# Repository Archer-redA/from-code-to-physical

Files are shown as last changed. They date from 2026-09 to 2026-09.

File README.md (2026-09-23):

# 从代码到实物 · 课程仓库

> **软件工程 · 张涛**
> 学期项目：**一体打印的可动机械键盘模型（macropad）**
> 已完成练习：**ARCHER 名字戒指**（3D 打印）



---

## 一、我是谁

- **专业**：软件工程
- **姓名**：张涛
- **GitHub**：[@Archer-redA](https://github.com/Archer-redA)

## 二、为什么选这门课

写了几年代码，但产出基本都停在屏幕里 —— 一个网页、一个脚本、一个跑在终端里的程序。它们能运行、能演示，但摸不到、拿不走。

我想试试另一条路：**让代码去驱动一个真实存在的东西**。按下按键，它要有反应；改一行配置，行为要真的跟着变。

这门课的名字恰好就是我想解决的问题 —— 「从代码到实物」。软件这一侧我相对熟悉，而电路、焊接、外壳、调试这些对我来说是全新的，正好是我想补的那一块。选它，是想给自己加一个约束：**必须动手，必须把东西真的做出来**，而不是又停在 `npm run dev`。

## 三、这学期想造什么

**一个一次打印成型、打出来就能动的机械键盘模型（macropad）。**
按下按键会下沉并自动回弹，转动旋钮会连续旋转 —— **不用组装、不用螺丝、不用五金件**。

> **第 1 周修订说明**：这个项目最初定的是「带电子功能的宏键盘」，我把它改成了
> **无电子功能的可动模型**。原因不是放弃，而是排优先级：原方案要串起主控、轴体、
> 焊接、固件、上位机工具，链路太长，依赖的零件也多，第一个学期很难在保证质量的前提下
> 全部做完。改成模型之后，同样的时间可以花在**机构设计**上 ——
> 柔性铰链、配合公差、可打印性。这些是更根本、也更容易被忽略的工程能力。
> 电子功能留作后续可选延伸，见需求文档第 6 节。

选它的理由：

1. **规模可控但难度不低。** 6 个键 + 1 个旋钮，尺寸不大，但「一体打印还要能动」
   是有真实技术门槛的 —— 见下方「这个项目难在哪」。
2. **逼着学公差。** 前面那个戒指是静态件，形状对就能打；这个项目必须处理
   **间隙、应变、桥接**，是从「建模」跨到「机构」的一步。
3. **一次打印、零装配。** 拿下来就是成品，非常适合演示，也不怕零件丢。
4. **仍然指向真实键盘。** 柔性机构、键位间距、结构刚度这些经验，
   以后真做一把能用的键盘时全部用得上。

### 这个项目难在哪

有一个本质矛盾必须在建模阶段解决：

> **柔性件要能动，周围就得是空的；但空的地方打印时没有支撑，材料会塌。**

传统解法是加支撑，但一加支撑就不是「一体打印、免组装」了。

**解法是把柔性梁做成「桥」** —— 两端都搭在实体墙上，中间悬空：

- **打印时**：它是一段桥，两端有支撑，桥接没问题 ✅
- **受力时**：它是一根两端固定的梁，中间能下沉、能回弹 ✅

代价是两端固定的梁比悬臂梁刚 8 倍，同样行程下应变高 8 倍，所以行程只能做到
**约 1.2mm**、应变控制在 **1.3% 以内**（PLA 反复弯曲的安全区）。

### 期末最低验收目标

- **至少 6 个按键**，每个都能按下并自动回弹，行程 ≥ 0.8mm
- **至少 1 个旋钮**，能连续旋转 360° 以上
- **一次打印成型**，不需要支撑材料，不需要任何组装
- 单键反复按压 **≥ 500 次**不失效

完整的验收标准、非目标与里程碑见 [`docs/需求与验收标准.md`](docs/需求与验收标准.md)。

## 四、仓库结构

```
.
├── README.md                  # 本文件
├── .gitignore
├── docs/
│   ├── 需求与验收标准.md        # 这个项目要做什么、怎么才算做完
│   ├── 工具链搭建.md            # 开发环境清单与逐项验证记录
│   └── 踩坑记录.md              # 卡得最久的问题 + 怎么解决的
├── hardware/
│   ├── ring/                  # ARCHER 名字戒指：建模源文件 + STL + 预览图 + 实拍
│   │   ├── ring.scad          # 参数化建模脚本（改这个）
│   │   ├── ring.stl           # 可直接切片的成品
│   │   ├── photo-printed.jpg  # 实物照片
│   │   └── README.md          # 尺寸、打印参数、校验记录、已知取舍
│   └── macropad/              # 学期项目：一体打印可动机械键盘模型
│       ├── key-test.scad      # 单键柔性机构测试件（先验证再放大）
│       ├── macropad.scad      # 整机（后续）
│       └── README.md          # 机构原理、应变计算、打印实测
└── tools/
    └── stl-check.js           # STL 水密性/流形校验工具
```

后续阶段计划增加的目录：

| 目录 | 用途 | 预计出现时间 |
|---|---|---|
| `hardware/macropad/` 旋钮测试件 | 旋转机构独立验证 | 第 3 周 |
| `hardware/macropad/` 整机 | 6 键 + 旋钮完整模型 | 第 4–5 周 |

## 五、开发环境（工具链）

本学期使用的工具链，均已实测通过：

| 用途 | 工具 | 版本 | 验证方式 |
|---|---|---|---|
| 版本控制 | Git | `2.20.1.windows.1` | `git --version` |
| 远程仓库 | GitHub（**SSH over 443**） | — | `ssh -T git@github.com` |
| 代码编辑器 | VS Code | `1.133.0` | `code --version` |
| 脚本 / 上位机工具 | Node.js / npm | `v24.14.1` / `11.11.0` | `node --version` |
| 三维建模 | OpenSCAD | `2026.09.16` | `openscad --info` |
| 3D 打印机 | Bambu Lab A1 mini | FDM / 0.4mm 喷头 | — |

> ⚠️ **本机 HTTPS 方式访问 GitHub/Gitee 不可用**，已改用 SSH。原因、复现步骤与解决方案见 [`docs/踩坑记录.md`](docs/踩坑记录.md)。

> ⚠️ **OpenSCAD 的 `textmetrics()` 是实验性函数，默认关闭。**
> 图形界面需在「编辑 → 首选项 → 功能(Features)」里勾选 `textmetrics`，
> 命令行渲染需加 `--enable=textmetrics`。详见 `hardware/ring/README.md`。

详细的环境清点、缺口与补齐计划见 [`docs/工具链搭建.md`](docs/工具链搭建.md)。

## 六、第一件实物：ARCHER 名字戒指

**已经真的打印出来了**（2026-09-23，Bambu Lab A1 mini）：

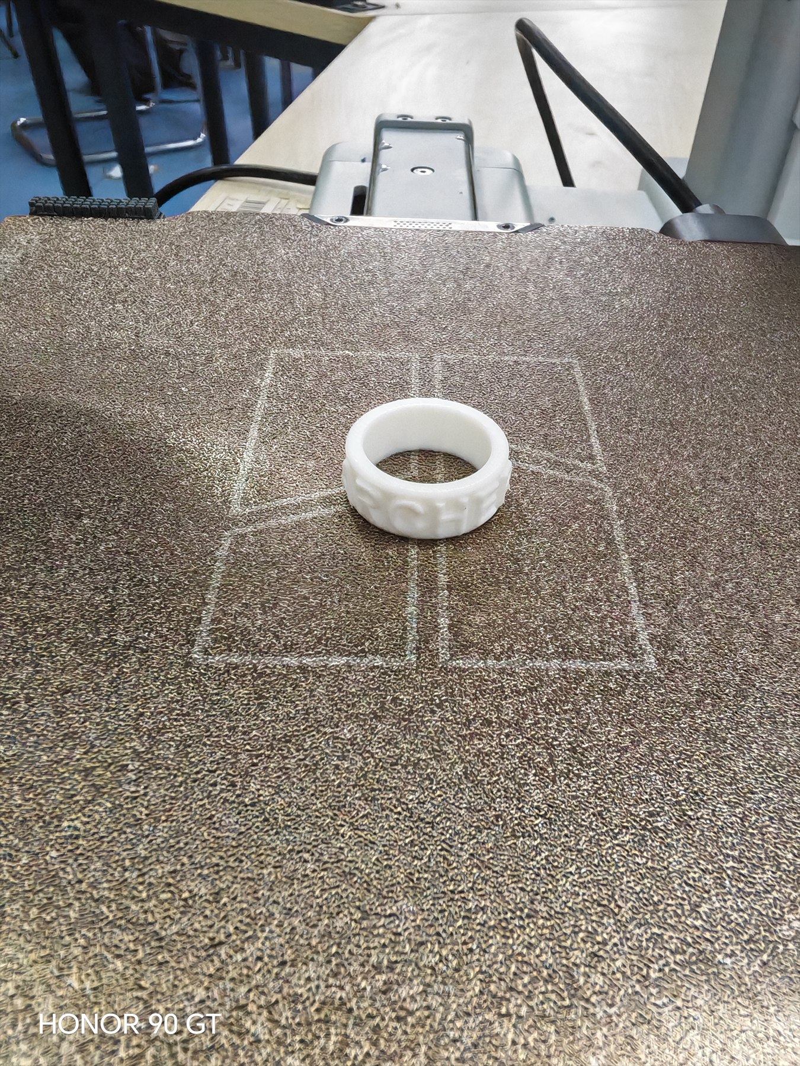
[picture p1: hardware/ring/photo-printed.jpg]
实物照片


这是建模阶段的渲染图，可以和上面的实物对比设计意图与实际结果：

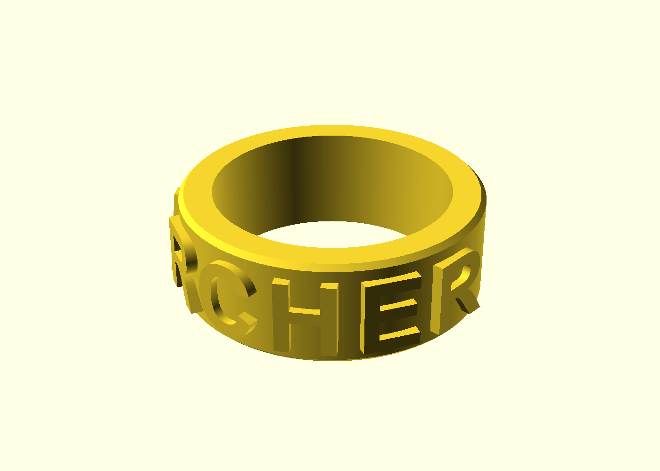
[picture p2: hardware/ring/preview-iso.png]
等轴测预览


把名字刻在戒指外圈，文字绕环 176°。**不是手动捏出来的，是写代码生成的** ——
整个模型由一个参数化脚本描述，改一个数字就能改尺寸、改文字。

| 项目 | 数值 |
|---|---|
| 外径 / 内径 / 带宽 / 壁厚 | 23 / 18 / 8 / 2.5 mm |
| 字高 / 凸起高度 | 5.5 mm / 0.6 mm |
| 网格体积 | 1335.8 mm³ |
| 预计耗材 | 约 1.66 g（PLA） |
| 水密性校验 | 开边 0、非流形 0、退化 0 —— **通过** |
| 实际打印 | 2026-09-23 完成，**一次成功**，耗时约 10 分钟，**效果良好** |

完整尺寸、打印参数、建模取舍与实拍记录见 [`hardware/ring/README.md`](hardware/ring/README.md)。

**这一步学到的三件事：**

1. **摆放方向决定成败。** 平放（轴向竖直）时文字全是垂直棱柱，零悬垂、不用支撑；
   立着放则下半圈整体是大角度悬垂，必然塌边。同一个模型，换个方向就是能用和不能用。
2. **打印机能打多细，是设计约束不是事后调参。** 0.4mm 喷头意味着笔画宽度不能低于
   0.8mm 左右，所以字必须用粗体 —— 这是设计阶段就要定下来的事。
3. **先校验再切片。** 自己写了个工具检查网格是否水密、是否流形，
   在源头把问题验掉，比在切片软件里看到莫名其妙的警告再回头查省事得多。
   这次模型一次打印成功、没出任何网格报错，验证了这一步是有效的。
4. **推荐参数和实际参数是两回事。** 我给的推荐层高是 0.12mm，但实际打印只花了约
   10 分钟，明显快于该预设的预期 —— 说明实际用的大概率是更快的档位。
   所以文档里「推荐值」和「实际值」必须分开记，否则下次照着推荐值打，
   永远不知道真实差异出在哪。

## 七、进度计划

| 周次 | 目标 | 状态 |
|---|---|---|
| 第 1 周 | 工具链搭建、仓库建立、需求与验收标准定稿 | ✅ 已完成 |
| 第 1 周 | 3D 建模环境就绪，完成 ARCHER 名字戒指并校验网格 | ✅ 已完成 |
| 第 1 周 | 戒指实际打印完成（A1 mini，一次成功） | ✅ 已完成 |
| 第 1 周 | 学期项目范围修订为「一体打印可动模型」 | ✅ 已完成 |
| 第 2 周 | **单键柔性机构测试件**：应变验证 + 500 次按压实测 | 🔄 进行中 |
| 第 3 周 | 旋钮机构独立验证 | ⬜ 未开始 |
| 第 4–5 周 | 整机建模：6 键 + 1 旋钮 | ⬜ 未开始 |
| 第 6 周 | 整机首次打印，F1–F8 全部验收 | ⬜ 未开始 |
| 第 7–8 周 | 迭代与加分项（段落感 / 旋钮定位 / 曲面键帽） | ⬜ 未开始 |
| 第 9 周 | 整机联调、文档收尾、期末演示准备 | ⬜ 未开始 |

---

*本仓库为《从代码到实物》课程学期项目仓库，将持续更新至期末。*

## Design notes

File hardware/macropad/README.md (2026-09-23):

# 单键柔性机构测试片

> **目的：在做整机之前，先验证「桥式柔性梁」这个机构能不能成立。**
> 一片上放三个变体，一次打印验证三种刚度。

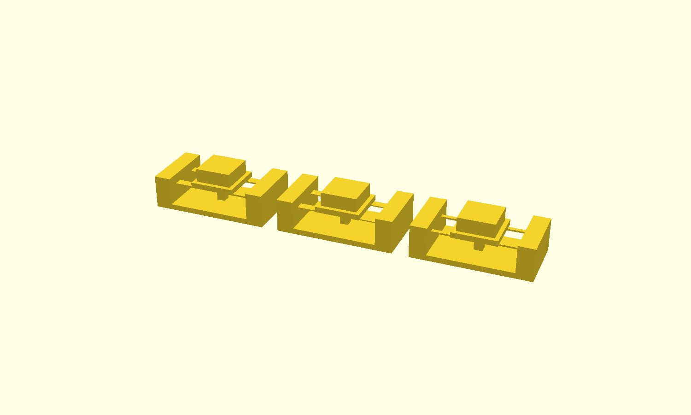
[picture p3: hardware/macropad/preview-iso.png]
等轴测


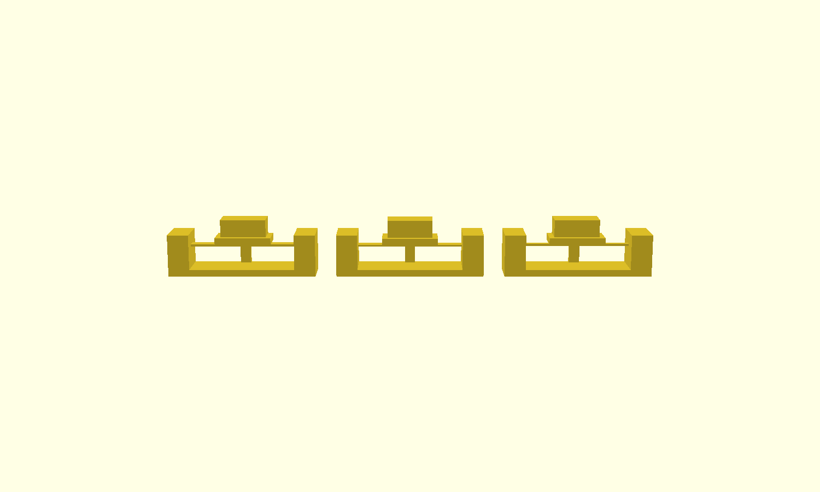
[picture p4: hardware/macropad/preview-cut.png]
剖视（露出梁、平台、止挡柱）


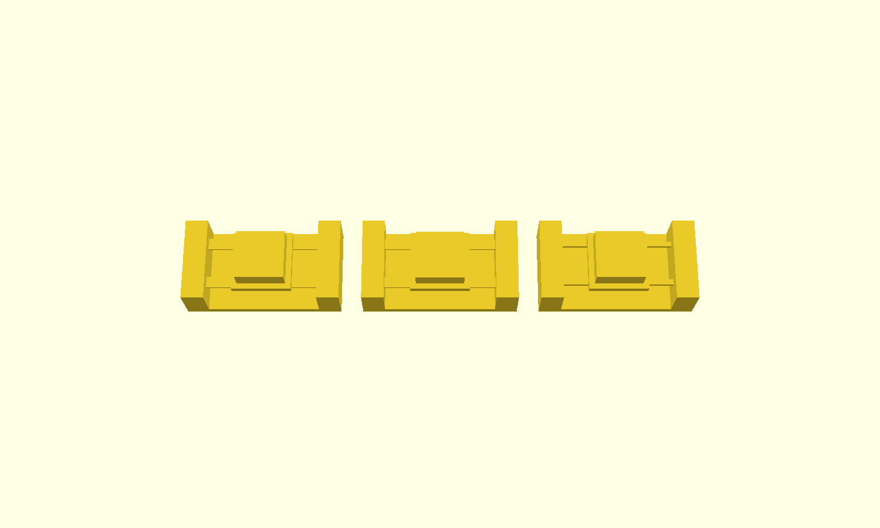
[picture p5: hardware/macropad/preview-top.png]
俯视（三个变体并排，共用一套打印参数）


## 要解决的核心矛盾

一体打印的可动件有一个本质矛盾：

> **柔性件要能动，周围就得是空的；但空的地方打印时没有支撑，材料会塌。**

加支撑就违背了「一体打印、免组装」的前提。

**解法：把柔性梁做成「桥」** —— 两端都搭在实体墙上，中间悬空。

| | 打印时 | 受力时 |
|---|---|---|
| 桥式梁 | 一段桥，两端有支撑，桥接没问题 ✅ | 一根两端固定的梁，中间能下沉、能回弹 ✅ |

代价：两端固定的梁比悬臂梁**刚 8 倍**（端部弯矩大），同样行程下应变也高 8 倍。

## 力学计算

两端固定梁 + 中央集中载荷：

```
弯曲刚度     I = b·t³ / 12
单根梁刚度   k = 192·E·I / L³
最大应变     ε = 12·t·δ / L²      （应变在两端的固定处最大）
```

PLA 取 E ≈ 3500 MPa，L = 30mm，设计行程 δ = 1.5mm：

| 变体 | 梁厚 t | 梁宽 b | 厚度层数 | 刚度 k | 压到底需 | ε @1.5mm | ε 达 1.5% 时行程 |
|---|---|---|---|---|---|---|---|
| **A** | 0.6 mm | 3.0 mm | 3 | 2.69 N/mm | 4.03 N | 1.20% | 1.88 mm |
| **B** | 0.4 mm | 3.0 mm | 2 | 0.80 N/mm | **1.19 N** | 0.80% | 2.81 mm |
| **C** | 0.6 mm | 1.5 mm | 3 | 1.34 N/mm | 2.02 N | 1.20% | 1.88 mm |

**参照**：Cherry MX 红轴 45 gf ≈ 0.45 N，黑轴 60 gf ≈ 0.6 N。
所以三个变体都偏硬，**B 最接近真实手感**，但它只有 2 层厚，是三个里最脆的 ——
这正是要实测的东西：**理论上最合适的设计，打印出来到底扛不扛得住。**

> **1.5% 应变的来历**：PLA 的断裂延伸率约 3–6%，但反复弯曲要考虑疲劳，
> 安全区取 1.5% 以下。**超过这个值不会立刻断，而是按几次之后出现永久变形或裂纹。**

## 止挡设计

首次打印**不要**去掉止挡柱。理由：

- 柔性梁的应变与实际行程成正比，**人手上按多重是不可控的**
- 没有止挡时，用力一按就可能把梁压到 3% 应变以上，直接产生永久变形
- 止挡柱让行程硬性停在设计值，**梁的应变不会超过计算值**

止挡柱从底板上长出来，柱顶与平台底面之间正好留出 `TRAVEL`。

> ⚠️ 第一版我漏了底板，导致止挡柱**完全悬空** —— 打出来会是一根 3×3×6.5mm 的
> 散件掉在壳子里，根本起不到止挡作用。这个问题是**用连通分量检测抓出来的**，
> 见下节。已修复。

## 校验

```bash
node ../../tools/stl-check.js key-test.stl 0.000001 3
```

```
triangles    : 432
size (mm)    : X=138  Y=22  Z=15.6
open edges   : 0
non-manifold : 0
degenerate   : 0
components   : 3 (expected 3)  sizes: 144 + 144 + 144 tris
结论          : 通过 —— 水密流形，可以打印
```

**第三个参数 `3` 是预期的连通分量数。** 这个参数是为一体打印件专门加的：

- 一体打印的零件**必须是连通的**，分开的壳体会变成打出来掉在里面的散件
- 而**切片软件不会为此报警** —— 它照样能把两个分离的实体切成两个独立的打印件，只是你不知道
- 所以必须自己验：每个变体是一个分量，三个变体就是三个分量
- **三个分量大小完全相等（144+144+144）**，说明每个变体内部都是连通的，止挡柱没掉

## 打印参数

| 参数 | 取值 | 说明 |
|---|---|---|
| 层高 | **0.2 mm** | **梁厚必须是层高的整数倍**，否则实际厚度不由你控制 |
| 支撑 | **关闭** | 桥式梁本来就是为了免支撑设计的 |
| 摆放 | 平放，与脚本朝向一致 | 不要旋转模型 |
| 墙数 | 3 | |
| 填充 | 15% | |

**层高这条特别重要**：变体 B 的梁设计厚度是 0.4mm，如果层高是 0.3mm，切片软件
只能给你 0.3 或 0.6mm —— 那刚度和应变跟算出来的完全对不上，测试就白做了。

## 怎么测

打印完成后，逐个按下三个键（从左到右是 A / B / C）：

| 检查项 | 合格标准 |
|---|---|
| 能否按下 | 三个都能明显下沉 |
| 回弹 | 松手后回到原位，无残留变形 |
| 相邻独立 | 按一个键时旁边的键不动（这一片是独立单元，主要测整机时用） |
| **按压 500 次** | 用拇指连续按，不出现白化、裂纹、断裂 |
| 手感排序 | 记录 A/B/C 哪个最舒服，与计算值对比 |

**建议把结果记回来**（改这一节就行）：

| 变体 | 实测手感 | 500 次后状态 |
|---|---|---|
| A | 待填 | 待填 |
| B | 待填 | 待填 |
| C | 待填 | 待填 |

## 参数怎么改

都在 `key-test.scad` 顶部：

```openscad
SPAN    = 30;     // 自由跨距 —— 应变 ∝ 1/L²，这是最有效的调节手段
TRAVEL  = 1.5;    // 设计行程 —— 同时决定止挡柱高度
VARIANTS = [      // [梁厚, 梁宽]
    [0.6, 3.0],
    [0.4, 3.0],
    [0.6, 1.5],
];
```

**跨距不能随便加大**：`SPAN` 同时是桥接长度，超过约 35mm 打印时会塌。
这是「机构设计」和「可打印性」直接冲突的地方 —— **也是这个项目最难的一处权衡**。

出图时控制台会打印每个变体的刚度、所需压力、应变，改完直接看数字即可。
`CUT = 1` 可以出一张剖视图，用来检查梁、平台、止挡柱的相对位置。

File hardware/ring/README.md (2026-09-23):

# ARCHER 名字戒指

第一件实物练习：把建模代码变成能打印出来的东西。
名字刻在戒指外圈，绕环约 **176°**。

## 实物

实物照片

*2026-09-23 打印完成。照片已压缩并清除 EXIF（原始 3000×4000 / 7.2MB →
1350×1800 / 933KB）。*

### 实际打印记录

| 项目 | 实际值 |
|---|---|
| 打印机 | Bambu Lab A1 mini，0.4mm 喷嘴 |
| 打印日期 | 2026-09-23 |
| **实际耗时** | **约 10 分钟** |
| 实际层高 | 未记录 |
| 实际耗材 | 未记录 |
| 实际用量 | 未称重 |

### 打印效果评估

**结论：整体效果不错，文字清晰可用。**

判断主要归功于两个设计选择：**环体做得厚、做得大**（壁厚 2.5mm、带宽 8mm、
外径 23mm），以及**字做得大**（字高 5.5mm）。前者让结构本身不脆弱、不易翘曲变形，
后者让笔画有足够宽度可供 FDM 完整还原。

这两点在建模阶段不是随手定的，是为了满足 0.4mm 喷头的可打印性下限（详见下节
「为什么字必须用粗体」）而刻意选的。**实测证明这个方向是对的**。

反过来说，如果把这个设计缩小一半（比如做成真正的细戒圈），文字笔画会同步缩到
0.5mm 左右，落到单条挤出线的宽度——那时候"能不能打清楚"就完全是另一个问题了。
**小尺寸不是等比缩小，是重新设计。**

> ⚠️ **注意耗时与推荐参数不匹配。**
> 上表「打印参数」一节推荐的是 `0.12mm Fine` 预设，按该预设估算这个件要二十几分钟。
> 实测 10 分钟完成，说明**实际很可能用的是默认的 `0.20mm Standard` 预设**（或更快的档位）。
> 层高越粗，0.6mm 的文字凸起只够 3 层，文字的侧面锐利度会下降。
> **下次打印建议显式确认层高设置**，并对比两种层高的文字清晰度差异。

### 渲染 vs 实物

| | 渲染图（建模输出） | 实物（实际打印） |
|---|---|---|
| 来源 | `preview-iso.png` | `photo-printed.jpg` |
| 用途 | 确认设计意图 | 确认真的做出来了 |

## 渲染图

等轴测预览

## 文件说明

| 文件 | 说明 |
|---|---|
| `ring.scad` | **参数化建模源文件**（改这个，不要改 STL） |
| `ring.stl` | 可直接切片的成品网格（二进制 STL，9720 三角形） |
| `photo-printed.jpg` | **实物照片**（已清除 EXIF） |
| `preview-iso.png` | 等轴测预览 |
| `preview-hero.png` | 主视角预览 |
| `preview-front.png` | 正侧视预览（名字正对镜头） |
| `preview-top.png` | 俯视预览（看内外径比例） |

## 设计尺寸（从 STL 实测，非设计值）

| 项目 | 数值 |
|---|---|
| 环体内径 | 18.00 mm |
| 环体外径 | 23.00 mm |
| 文字凸起后最大半径 | 24.76 mm（含字母两端） |
| 带宽 | 8.00 mm |
| 壁厚 | 2.50 mm |
| 字高 | 5.50 mm |
| 文字凸起高度 | 0.60 mm |
| 文字绕环角度 | 176.0° |
| 网格体积 | 1335.8 mm³ |
| 预计耗材 | 约 **1.66 g**（PLA，密度 1.24 g/cm³） |
| 预计耗材长度 | 约 555 mm（1.75mm 线径） |
| 网格三角形 | 9720 |
| 水密性 | 开边 0、非流形 0、退化 0（校验通过） |

耗材量是按网格体积换算的。**打印时间请以 Bambu Studio 切片后的估算为准。**

## 打印参数（推荐值，Bambu Lab A1 mini）

| 参数 | 取值 | 原因 |
|---|---|---|
| 喷头 | 0.4 mm | A1 mini 标配 |
| 层高 | **0.12 mm** | 文字只有 0.6mm 凸起，层高太粗会看不出层次 |
| 摆放 | **平放**（戒指轴向竖直） | 关键：这样文字全是垂直棱柱，Z 方向没有悬垂面 |
| 支撑 | **关闭** | 平放后不需要；开了反而会粘在字上 |
| 墙数 | 4 | 壁厚 2.5mm，4 圈墙就基本填满了 |
| 填充 | 15% | 实际几乎全由墙填满，填充率影响很小 |
| 底座(Brim) | 3 mm（可选） | 首层是个 23mm 的圆环，附着力够，加个 Brim 更保险 |

> ⚠️ **不要立着放。** 立放时环的下半圈整体是大角度悬垂，必然塌边。
> 平放是这个小件唯一合理的摆法。

## 为什么字必须用粗体

这是 FDM 打印能不能看清文字的硬约束：

- A1 mini 喷头 0.4mm，单条挤出线宽约 0.42mm
- 实测 Arial Bold 在字高 5.5mm 时，竖笔画约 **1.07mm** ≈ 2.5 条挤出线 → 能连住
- 同样的字高换成常规字重，笔画只剩约 0.65mm ≈ 1.5 条线 → 打印时容易断线、糊成一团

所以 `FONT` 参数一定要带 `:style=Bold`。

## 怎么改

所有尺寸都在 `ring.scad` 顶部，改一个数重新出图即可，不需要重画：

```openscad
INNER_D = 18;        // 内径
WALL    = 2.5;       // 壁厚
BAND    = 8;         // 带宽
TEXT    = "ARCHER";  // 刻什么字
CAP     = 5.5;       // 字高
EMBOSS  = 0.6;       // 凸起高度
```

**改完记得核对弧长**：字太长会绕环超过一圈，字与字会自己压在一起。
出图时 OpenSCAD 会打印一行 `TEXT_SPAN_DEG`，**这个值不要超过 330°**，留出空隙。

## 怎么重新生成

```bash
# 生成 STL（二进制）
openscad --enable=textmetrics --export-format binstl \
         -o ring.stl ring.scad

# 生成预览图
openscad --enable=textmetrics --render --imgsize=1400,1000 \
         --projection=p --autocenter --viewall \
         --camera=0,0,0,60,0,25,60 -o preview-iso.png ring.scad
```

> ⚠️ **`--enable=textmetrics` 不能省。**
> `textmetrics()` 在 OpenSCAD 里是实验性内置函数，默认关闭。
> 图形界面里打开方式：**编辑 → 首选项 → 功能(Features) → 勾选 textmetrics**。
> 没有它的话，脚本会自动回退到文件内烘焙好的字宽表，仍然能出图，
> 但遇到表里没有的字符会按估算宽度排，字距会不准。

## 校验

打印前用仓库自带的工具验过水密性：

```bash
node ../tools/stl-check.js ring.stl
```

结果：

```
triangles    : 9720
open edges   : 0
non-manifold : 0
degenerate   : 0
CONCLUSION   : 通过 —— 水密流形，可以打印
```

**为什么要做这一步**：切片软件对非水密网格的处理方式不一致，可能出现
「有的地方凭空多一层墙」或者直接报错。先在源头验掉，比在切片软件里
看到莫名其妙的警告再回头查省事得多。

**事后验证**：这个模型确实一次打印成功，没有出现网格相关的报错，说明校验是有效的。

## 已知取舍

建模时明确知道、但选择接受的地方，记下来免得以后忘了：

1. **每个字母是一块切平面上的平板，不是真正贴着圆柱弯曲的。**
   代价是字母两端的凸起比中间多约 0.28mm（0.6mm → 0.88mm），
   看上去字的两端略高一点点。
   要做成完全等高的弯曲文字，得把每个字母切成上百个薄片再绕圆周旋转，
   会引入新的接缝问题，而且网格量大一个数量级。
   对这个尺寸的装饰件，0.28mm 的差异在 0.4mm 喷头下基本看不出来，选了简单可靠的方案。

2. **内圈边缘没有倒角。** 外圈上下棱有 0.4mm 倒角，内圈是直角。
   反正是戴着玩的装饰件，内圈不做处理不影响打印。

3. **不支持中文。** 中文笔画密，5.5mm 字高下笔画只有 0.3mm 左右，
   FDM 打印必然糊成一团，要刻中文得换光固化，或者把戒指做大好几倍。

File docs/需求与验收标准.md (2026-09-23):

# 需求与验收标准：一体打印可动机械键盘模型

> 本文档定义本学期项目的**范围**与**完成标准**。
> 目的：避免「做了一半说不清算不算做完」，也让每一周的进展都能对照检查。
>
> ⚠️ **第 1 周修订**：本项目原定为「带电子功能的宏键盘」，现改为
> **一体打印的可动机械模型（无电子功能）**。原方案需要主控、轴体、焊接、
> 固件、上位机工具，链路长、依赖多的零件，第一学期难以在保证质量的前提下完成。
> 改为模型后，可以在同样的时间里把**机构设计**这一块做扎实 ——
> 柔性铰链、配合公差、可打印性，这些是更根本的工程能力。
> 电子功能不是被放弃，而是**留作后续可选延伸**（见第 6 节）。

## 1. 一句话描述

一个打出来就能用的机械键盘模型：**按下按键会下沉并自动回弹，转动旋钮会连续旋转**。
整体一次打印成型，不需要组装、不需要螺丝、不需要任何五金件。

## 2. 目标用户

我自己，以及任何想看看「柔性机构能打印到什么程度」的人。放在桌上是个摆件，拿起来能玩。

## 3. 必做功能（期末必须全部达成）

| 编号 | 功能 | 验收方式 |
|---|---|---|
| F1 | **至少 6 个按键**，每个都能按下并自动回弹 | 逐个按下，松手后全部回到原位，无卡滞 |
| F2 | **至少 1 个旋钮**，能连续旋转 | 手动旋转 360° 以上，转动顺畅无卡死 |
| F3 | **一次打印成型**，不需要任何组装 | 从打印板上取下来即为成品，不使用胶水、螺丝、卡扣装配 |
| F4 | **不需要支撑材料** | 切片时支撑设为关闭，仍能成功打印 |
| F5 | 按键**行程 ≥ 0.8 mm** | 用游标卡尺测量按下前后的高度差 |
| F6 | 每个键**能被单独按下**，不影响相邻键 | 按下一个键时，相邻键的高度变化 < 0.1 mm |
| F7 | 柔性件**反复按压不失效** | 单键连续按压 **≥ 500 次**，不出现裂纹、断裂或永久变形 |
| F8 | 整机外观完整，有外壳形态 | 看得出是一个键盘，键位排列整齐 |

## 4. 加分功能（时间允许才做，不列入必做）

- 按键有**段落感**（按下去有"咔哒"一下的手感，而不是线性下沉）
- 旋钮带**阻尼或分段定位**（转动时有清晰的"格"感）
- 按键表面有**曲面凹陷**，贴合手指
- 外壳底面有**防滑脚垫凹槽**
- 多色打印（有 AMS 的话）

## 5. 明确不做（非目标）

划清范围，避免项目失控：

- ❌ 不做电路、不焊线、不接主控
- ❌ 不做固件、不做 HID 上报、不做免驱识别
- ❌ 不做上位机配置工具
- ❌ 不做真实轴体的兼容（不预留 14×14mm 轴孔）
- ❌ 不追求真实键盘的 3–4mm 行程与手感，0.8–1.5mm 即可
- ❌ 不做多零件装配，坚持一次成型

## 6. 后续可选延伸（不在本学期范围）

如果模型做完还有余力，可以按这个顺序往上加：

1. **改成可插真轴的外壳** —— 需要重做定位板（14×14mm 轴孔、1.5mm 板厚）
2. **加电子功能** —— 手焊直连，RP2040 / Pro Micro 类小板
3. **加固件与上位机** —— 按键映射、配置文件热加载

## 7. 里程碑

| 阶段 | 目标 | 通过标准 |
|---|---|---|
| 第 1 周 | 需求定稿、建模脚本建立 | 本文档定稿，仓库结构就绪 |
| 第 2 周 | **单键测试片**验证柔性机构 | 应变计算通过 + 实物按压 ≥ 500 次不失效 |
| 第 3 周 | 旋钮机构验证 | 独立测试件旋转顺畅，无卡死 |
| 第 4–5 周 | 整机建模 | 6 键 + 1 旋钮完整模型，网格校验通过 |
| 第 6 周 | 整机首次打印 | F1–F8 全部通过 |
| 第 7–8 周 | 迭代与加分项 | 至少完成一项加分功能 |
| 第 9 周 | 收尾 | 文档完整、实拍入库、可演示 |

## 8. 风险与应对

| 风险 | 影响 | 应对 |
|---|---|---|
| **柔性件断裂** | F1/F7 直接不通过 | 先做单键测试片把应变验到 <1.5%；PLA 偏脆，不行就换 PETG |
| **桥接塌陷** | 柔性梁打印出来就废了 | 自由跨距控制在 30mm 以内；必要时把梁加宽改善桥接 |
| **按键互相干涉** | F6 不通过 | 键间留足间隙；相邻键的柔性梁走不同高度层 |
| **实际手感与计算不符** | 需要多次重打 | 参数化脚本，改一个数就能重出；测试片打印成本低 |
| **层间结合强度不足** | 梁从层间裂开 | 柔性梁的弯曲方向尽量落在层内；提高打印温度改善层间结合 |

---

*最后更新：第 1 周（项目范围由「功能宏键盘」修订为「可动模型」）*

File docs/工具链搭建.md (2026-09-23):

# 工具链搭建与验证记录

> 记录时间：第 1 周
> 目的：把本学期开发环境的**实际状态**写清楚 —— 装了什么、什么版本、怎么验证的、还缺什么。

## 1. 最终工具链清单

| 用途 | 工具 | 版本 | 安装位置 |
|---|---|---|---|
| 版本控制 | Git | `2.20.1.windows.1` | `D:\program\git\git\Git\cmd\git.exe` |
| 远程仓库 | GitHub | — | [Archer-redA/from-code-to-physical](https://github.com/Archer-redA/from-code-to-physical) |
| 推送协议 | SSH（**走 443 端口**） | — | `~/.ssh/config` |
| 代码编辑器 | VS Code | `1.133.0` | — |
| 运行时 / 上位机工具 | Node.js | `v24.14.1` | — |
| 包管理 | npm | `11.11.0` | — |

## 2. 逐项验证记录

以下命令均已实际执行并确认输出，不是「装完就算」。

### 2.1 Git 可用

```console
$ git --version
git version 2.20.1.windows.1
```

⚠️ **已知问题**：这个版本发布于 2018 年，偏旧。日常能用的影响包括：
不支持 `git switch` / `git restore`（2.23+）、不支持 `init.defaultBranch` 配置项（2.28+）。
目前不影响提交与推送，暂不升级；如果后续协作出现兼容问题，再升级到最新版。

### 2.2 GitHub 身份认证通过（走 SSH）

```console
$ ssh -T git@github.com
Hi Archer-redA! You've successfully authenticated, but GitHub does not provide shell access.
```

这条输出说明 SSH 密钥已被 GitHub 接受，**可以正常推送**。

### 2.3 SSH 走 443 端口的配置

`~/.ssh/config` 内容：

```
Host github.com
    Hostname ssh.github.com
    Port 443
    User git
```

**为什么这样配**：GitHub 的标准 SSH 端口是 22，但在国内网络环境下 22 端口经常被阻断或超时。
GitHub 官方提供了 `ssh.github.com:443` 作为备用入口，把 SSH 流量伪装成 HTTPS 流量出去，
绕开对 22 端口的限制。这是这台机器上必须保留的配置。

### 2.4 远程仓库连通性

```console
$ git ls-remote https://github.com/git/git.git HEAD
3bc0341126508f78f5869cbfc0005e987efdf0c7	HEAD
```

能正常拉到远程引用，说明网络出口与 TLS 都没问题。

## 3. 环境缺口与补齐计划

诚实记录当前**还没有**的东西，以及打算什么时候补：

| 缺口 | 影响 | 补齐计划 |
|---|---|---|
| **未安装 Python** | 上位机配置工具如果走 Python 路线会做不了 | 第 5–6 周做上位机工具时再装；也可以直接用 Node.js 写，避免额外依赖 |
| **未安装嵌入式开发工具链**（Arduino IDE / PlatformIO / ESP-IDF） | 固件暂时无法编译烧录 | 硬件选型定下来之后立刻装，第 2–3 周内完成 |
| Git 版本偏旧（2.20.1） | 部分新命令不可用 | 视情况升级，非阻塞 |
| 未安装 `core.quotepath` 相关设置 | git 输出中文文件名时会显示成 `\346\226\207...` 八进制转义，不易读 | 已在本仓库内设置 `core.quotepath = false`（见第 4 节） |

> **换行符说明**：`core.autocrlf = true`，来源是系统级配置 `C:\ProgramData\Git\config`
> （Git for Windows 的默认值）。效果是：工作区里是 CRLF，仓库里存 LF。
> 对本项目这种以 Markdown 文档为主的情况是可接受的默认行为，不做改动，
> 但要知道这个差异存在 —— 以后如果出现「我明明没改这个文件，git 却说它被改了」，
> 大概率就是换行符造成的。

> 说明：本项目的上位机工具优先考虑用 **Node.js** 实现 —— 这台机器上 Node 环境是现成可用的，
> 可以少装一个运行时，属于「用已有的工具解决问题」。

## 4. 本仓库的 git 设置

```bash
# 让 git 直接显示中文文件名，而不是八进制转义
git config core.quotepath false
```

设置前后的区别：

```console
# 设置前
docs/\351\234\200\346\261\202\344\270\216\351\252\214\346\224\266\346\240\207\345\207\206.md

# 设置后
docs/需求与验收标准.md
```

因为本仓库里有中文文件名，这个设置在查看 `git log --stat`、`git status` 时很关键，
否则满屏转义字符根本看不出改了哪个文件。

## 5. 日常工作机制

```bash
# 看当前状态
git status

# 提交一次改动
git add <文件>
git commit -m "docs: 说明这次改了什么"

# 推到远程
git push
```

约定：

- **提交信息**用 `类型: 说明` 的格式，类型包括 `feat` / `fix` / `docs` / `chore` / `refactor`。
- **每次提交只做一件事**，不要把不相关的改动混在一起。
- 仓库保持**公开可见**，方便老师随时查看进度。

## 6. 参考资料

- GitHub 官方文档：Using SSH over the HTTPS port
- Git 官方文档：`git config`（`core.autocrlf` / `core.quotepath`）

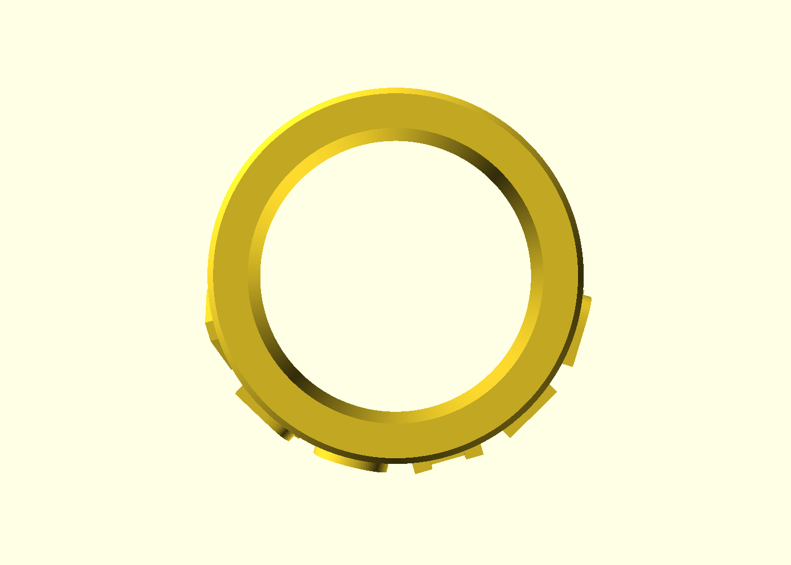
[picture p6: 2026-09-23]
hardware/ring/preview-top.png

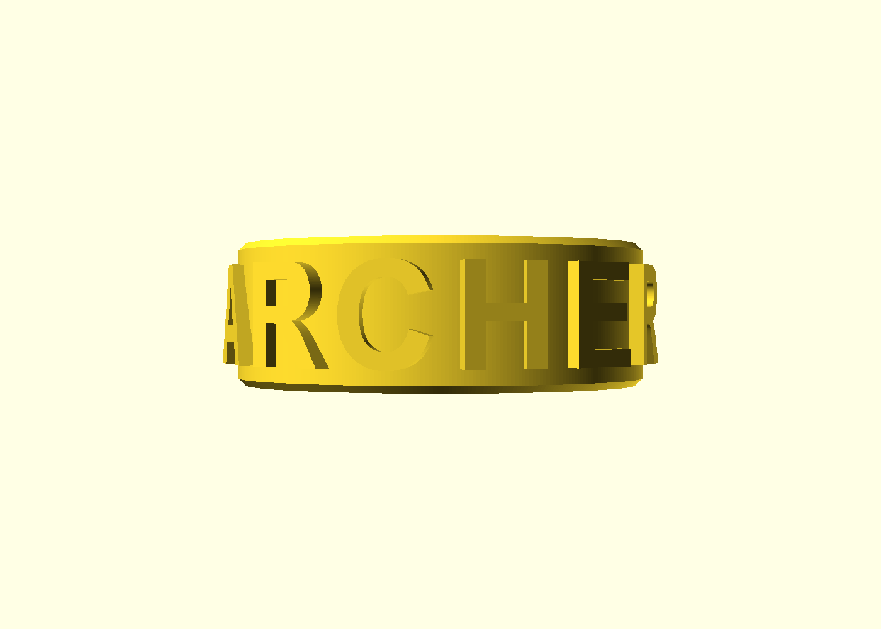
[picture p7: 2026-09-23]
hardware/ring/preview-front.png

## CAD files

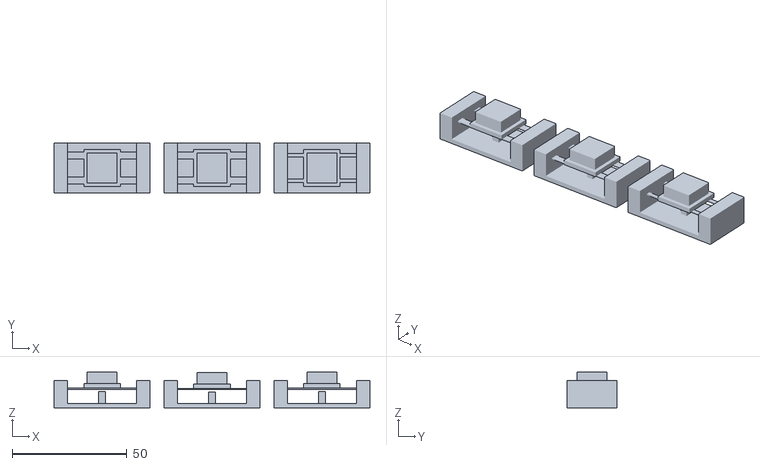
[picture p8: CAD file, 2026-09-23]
hardware/macropad/key-test.stl
138.0 x 22.0 x 15.6

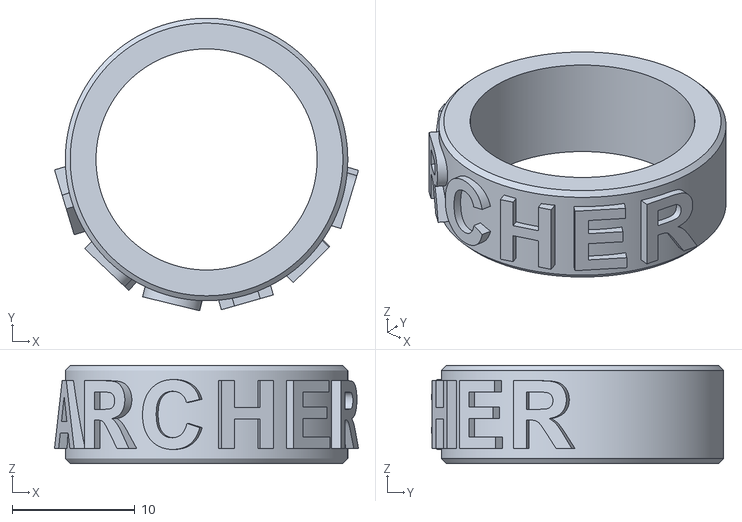
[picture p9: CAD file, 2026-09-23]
hardware/ring/ring.stl
24.8 x 23.8 x 8.00

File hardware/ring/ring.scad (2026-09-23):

/* ==========================================================================
   ARCHER 名字戒指 —— 参数化模型
   ==========================================================================
   打印机 : Bambu Lab A1 mini (FDM, 0.4mm 喷头)
   摆放   : 平放（戒指轴向竖直）。这样文字全部是垂直棱柱，Z 方向没有悬垂面，
            不需要开支撑；立着放则下半圈整体是悬垂，必崩。
   字重   : 必须粗体。实测字高 5.5mm 时 Arial Bold 竖笔画约 1.07mm，
            约等于 2.5 条挤出线，打印不会断线；常规字重只有约 0.65mm。

   ---------------------------------------------------------------------------
   重要：本文件用到 textmetrics()，它是 OpenSCAD 的实验性内置函数。
     · 命令行：openscad --enable=textmetrics -o ring.stl ring.scad
     · 图形界面：编辑 → 首选项 → 功能(Features) → 勾选 textmetrics，
                 否则打开本文件会报 "unknown function 'textmetrics'"。
     如果没启用，脚本会自动回退到文件内烘焙好的字宽表（见 W1），
     仍然能正确出图，只是不再随字体变化自动适配。

   如果换了字体，请重新标定 CAP_PER_SIZE（见下方说明）。
   ========================================================================== */

// ---------------------------- 可调参数 ----------------------------
INNER_D = 18;        // 内径 (mm)
WALL    = 2.5;       // 壁厚 (mm)
BAND    = 8;         // 带宽 (mm)
CHAMFER = 0.4;       // 上下外棱倒角 (mm)

TEXT    = "ARCHER";           // 要刻的字（支持任意字符串）
CAP     = 5.5;                // 字高：大写字母实际高度 (mm)
FONT    = "Arial:style=Bold"; // 粗体，勿改成常规字重
EMBOSS  = 0.6;                // 文字凸起高度 (mm)
EMBED   = 0.8;                // 文字嵌进环体的深度 (mm)，必须足够大，
                              // 否则字符两端会与环体脱开

FN      = 360;               // 环体圆周细分

// 标定值：字高 / text(size=) 的实测比值。
// 在本机 Arial Bold 上用 calib.scad 实测得到：size=10 时字高 = 9.941mm。
// 换字体后请重测，方法：渲染 calib.scad，量 H 的 Y 方向包围盒高度 / size。
CAP_PER_SIZE = 0.9941;

ONLY = 0;   // 0=整体 1=只要环体 2=只要文字（分件校验用）

// ---------------------------- 推导值 ----------------------------
R_IN  = INNER_D / 2;
R_OUT = R_IN + WALL;
FS    = CAP / CAP_PER_SIZE;   // 字号 = 字高 / 标定比
R_TXT = R_OUT - EMBED;        // 文字背面所在半径
Z_MID = BAND / 2;
DEPTH = EMBOSS + EMBED;       // 挤出深度；前面所在半径恰好 = R_OUT + EMBOSS

$fa = 2;
$fs = 0.2;

// ---------------------------- 环体 ----------------------------
module band() {
    rotate_extrude(angle = 360, $fn = FN)
        polygon(points = [
            [R_IN,            0],
            [R_OUT - CHAMFER, 0],
            [R_OUT,           CHAMFER],
            [R_OUT,           BAND - CHAMFER],
            [R_OUT - CHAMFER, BAND],
            [R_IN,            BAND],
        ]);
}

// ---------------------------- 文字 ----------------------------
chars = [for (i = [0 : len(TEXT) - 1]) TEXT[i]];

// --- 字宽表：Arial Bold 在本机实测，size=1 时的 advance ---
// 仅作 textmetrics 不可用时的回退。数值已核对过 Arial Bold 标准度量
// （E/A = 0.9236 对 667/722 = 0.9238，W/A = 1.307 对 944/722 = 1.3075）。
W1 = [
    [" ", 0.38588], ["A", 1.00301], ["B", 1.00301], ["C", 1.00301],
    ["D", 1.00301], ["E", 0.92638], ["F", 0.84839], ["G", 1.08032],
    ["H", 1.00301], ["I", 0.38588], ["J", 0.77243], ["K", 1.00301],
    ["L", 0.84839], ["M", 1.15696], ["N", 1.00301], ["O", 1.08032],
    ["P", 0.92638], ["Q", 1.08032], ["R", 1.00301], ["S", 0.92638],
    ["T", 0.84839], ["U", 1.00301], ["V", 0.92638], ["W", 1.31090],
    ["X", 0.92638], ["Y", 0.92638], ["Z", 0.84839], ["a", 0.77243],
    ["b", 0.84839], ["c", 0.77243], ["d", 0.84839], ["e", 0.77243],
    ["f", 0.46251], ["g", 0.84839], ["h", 0.84839], ["i", 0.38588],
    ["j", 0.38588], ["k", 0.77243], ["l", 0.38588], ["m", 1.23495],
    ["n", 0.84839], ["o", 0.84839], ["p", 0.84839], ["q", 0.84839],
    ["r", 0.54050], ["s", 0.77243], ["t", 0.46251], ["u", 0.84839],
    ["v", 0.77243], ["w", 1.08032], ["x", 0.77243], ["y", 0.77243],
    ["z", 0.69445], ["0", 0.77243], ["1", 0.77243], ["2", 0.77243],
    ["3", 0.77243], ["4", 0.77243], ["5", 0.77243], ["6", 0.77243],
    ["7", 0.77243], ["8", 0.77243], ["9", 0.77243], [".", 0.38588],
    [",", 0.38588], ["-", 0.46251], ["_", 0.77243], ["+", 0.81109],
    ["&", 1.00301], ["!", 0.46251], ["?", 0.84839],
];

function w1(c, i = 0) =
    i >= len(W1) ? 0.75
  : W1[i][0] == c ? W1[i][1]
  : w1(c, i + 1);

// 探测 textmetrics 是否可用（未启用时返回 undef）
TM     = textmetrics("H", size = 1, font = FONT);
HAS_TM = !is_undef(TM);

adv = [for (c = chars)
           HAS_TM ? textmetrics(c, size = FS, font = FONT).advance[0]
                  : w1(c) * FS];

function cumsum(v, i = 0, acc = 0) =
    i >= len(v) ? [] : concat([acc], cumsum(v, i + 1, acc + v[i]));

function total(v, i = 0) =
    i >= len(v) ? 0 : v[i] + total(v, i + 1);

off = cumsum(adv);
TOT = total(adv);

// 出图时打印关键尺寸，方便核对（不参与几何）
echo(TEXTMETRICS_AVAILABLE = HAS_TM);
echo(FONT_SIZE = FS);
echo(TEXT_TOTAL_WIDTH_MM = TOT);
echo(TEXT_SPAN_DEG = TOT / R_TXT * 180 / PI);
echo(MAX_RADIUS_MM = R_OUT + EMBOSS);

// 每个字符单独放置；角度按"弧长 = 字距"分配，保证字符间距均匀。
module glyph(ch, xoff) {
    ang = xoff / R_TXT * 180 / PI;
    rotate([0, 0, ang])
        translate([0, -R_TXT, Z_MID])
            rotate([90, 0, 0])
                linear_extrude(height = DEPTH)
                    text(ch, size = FS, font = FONT,
                         halign = "center", valign = "center");
}

module name_text() {
    for (i = [0 : len(chars) - 1])
        glyph(chars[i], off[i] + adv[i] / 2 - TOT / 2);
}

// ---------------------------- 总装 ----------------------------
if (ONLY == 0) {
    union() { band(); name_text(); }
} else if (ONLY == 1) {
    band();
} else {
    name_text();
}

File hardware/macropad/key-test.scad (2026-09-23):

/* ==========================================================================
   单键柔性机构测试片 —— 一体打印，无组装，无支撑
   ==========================================================================
   目的：在做整机之前，先验证「桥式柔性梁」这个机构能不能成立。

   核心思路（解决打印与运动的矛盾）：
     柔性梁两端都搭在实体墙上，中间悬空。
       · 打印时 —— 它是一段桥，两端有支撑，桥接没问题
       · 受力时 —— 它是一根两端固定的梁，中间能下沉、能回弹
     这样既不用支撑，又能动。

   一片上放三个变体，一次打印验证三种刚度，比打三次省时间。

   力学依据（两端固定梁，中央集中载荷）：
     刚度      k = 192·E·I / L³        I = b·t³/12
     最大应变  ε = 12·t·δ / L²         （应变在两端的固定处最大）
   导出值会打在控制台上，出图时对照。

   打印要求：
     · 层高 0.2mm（梁厚必须是层高的整数倍，否则实际厚度不由你控制）
     · 支撑：关闭
     · 摆放：平放，和脚本朝向一致，不要旋转
   ========================================================================== */

// ---------------------------- 可调参数 ----------------------------
SPAN    = 30;     // 自由跨距 mm —— 桥接长度，也是柔性梁的有效长度
WALL_T  = 6;      // 两端墙厚度 mm
WALL_H  = 12;     // 墙高 mm
UNIT_W  = 22;     // 单片宽度 mm
GAP     = 6;      // 变体之间的间隔 mm
FLOOR_T = 2;      // 底板厚度 mm —— 让止挡柱有根，否则它会变成散件

BEAM_Y  = 5.5;    // 两根梁的中心距中轴 mm
BEAM_Z  = 8;      // 梁底面高度 mm（下方全空，靠桥接打印）

PLAT    = 16;     // 浮动平台边长 mm
PLAT_T  = 2;      // 平台厚度 mm
KEY     = 13;     // 键帽边长 mm
KEY_H   = 5;      // 键帽高度 mm

TRAVEL  = 1.5;    // 设计行程 mm —— 由止挡柱限制，防止按压过度把梁压坏
STOP    = 3;      // 止挡柱截面 mm

CUT     = 0;      // 1 = 沿中轴剖开，用于展示内部机构（只影响预览，不影响出图）

E_PLA   = 3500;   // PLA 弹性模量 MPa

// [梁厚 t, 梁宽 b]
VARIANTS = [
    [0.6, 3.0],   // A 基准
    [0.4, 3.0],   // B 更薄 -> 最软
    [0.6, 1.5],   // C 更窄 -> 中等
];
LABELS = ["A", "B", "C"];

LEN = 2 * WALL_T + SPAN;
TOTAL_LEN = len(VARIANTS) * LEN + (len(VARIANTS) - 1) * GAP;

$fa = 2;
$fs = 0.2;

// ---------------------------- 工具 ----------------------------
module box(x0, y0, z0, x1, y1, z1) {
    translate([x0, y0, z0]) cube([x1 - x0, y1 - y0, z1 - z0]);
}

// ---------------------------- 一个变体 ----------------------------
module unit(bt, bw) {
    // 底板：本身不参与机构，只负责把止挡柱连成一体
    // 梁在 z=BEAM_Z 处下沉最多 TRAVEL，与底板顶面(z=FLOOR_T)之间留有大余量
    box(0, 0, 0, LEN, UNIT_W, FLOOR_T);

    // 墙体
    box(0, 0, 0, WALL_T, UNIT_W, WALL_H);
    box(WALL_T + SPAN, 0, 0, LEN, UNIT_W, WALL_H);

    // 两根柔性梁：两端搭在墙上，中间悬空 -> 打印时是桥，受力时是固定梁
    for (s = [1, -1]) {
        box(WALL_T, UNIT_W / 2 + s * BEAM_Y - bw / 2, BEAM_Z,
            WALL_T + SPAN, UNIT_W / 2 + s * BEAM_Y + bw / 2, BEAM_Z + bt);
    }

    // 止挡柱：从底板上长出来，柱顶与平台底面之间正好留出 TRAVEL
    // 这样按压到底会被硬性挡住，梁的应变不会超过设计值
    box(WALL_T + SPAN / 2 - STOP / 2, UNIT_W / 2 - STOP / 2, FLOOR_T,
        WALL_T + SPAN / 2 + STOP / 2, UNIT_W / 2 + STOP / 2, BEAM_Z + bt - TRAVEL);

    // 浮动平台：坐在两根梁上，两梁之间跨 9mm，桥接可打
    box(WALL_T + SPAN / 2 - PLAT / 2, UNIT_W / 2 - PLAT / 2, BEAM_Z + bt,
        WALL_T + SPAN / 2 + PLAT / 2, UNIT_W / 2 + PLAT / 2, BEAM_Z + bt + PLAT_T);

    // 键帽
    box(WALL_T + SPAN / 2 - KEY / 2, UNIT_W / 2 - KEY / 2, BEAM_Z + bt + PLAT_T,
        WALL_T + SPAN / 2 + KEY / 2, UNIT_W / 2 + KEY / 2, BEAM_Z + bt + PLAT_T + KEY_H);
}

// ---------------------------- 总装 ----------------------------
module all() {
    for (i = [0 : len(VARIANTS) - 1]) {
        translate([i * (LEN + GAP), 0, 0])
            unit(VARIANTS[i][0], VARIANTS[i][1]);
    }
}

if (CUT == 1) {
    // 沿中轴剖开，露出梁、平台、止挡柱的相互关系
    intersection() {
        all();
        box(-1, -1, -1, TOTAL_LEN + 1, UNIT_W / 2, 100);
    }
} else {
    all();
}

// ---------------------------- 力学输出 ----------------------------
echo("=== 设计参数 ===");
echo(SPAN = SPAN, TRAVEL = TRAVEL, BEAM_Z = BEAM_Z);
echo(TOTAL_LEN = TOTAL_LEN, TOTAL_W = UNIT_W);
echo("");
echo("=== 各变体力学（E_PLA = 3500 MPa）===");
for (i = [0 : len(VARIANTS) - 1]) {
    bt = VARIANTS[i][0];
    bw = VARIANTS[i][1];
    I  = bw * pow(bt, 3) / 12;
    kb = 192 * E_PLA * I / pow(SPAN, 3);   // 单根梁刚度
    kt = 2 * kb;                            // 两根梁并联
    F  = kt * TRAVEL;                       // 压到底需要的力
    ep = 12 * bt * TRAVEL / pow(SPAN, 2);   // 最大应变
    // 达到 1.5% 应变（PLA 反复弯曲的安全上限）对应的行程
    dmax = 0.015 * pow(SPAN, 2) / (12 * bt);
    echo(str("变体 ", LABELS[i],
             "  t=", bt, "mm b=", bw, "mm",
             "  | 厚度层数=", bt / 0.2,
             "  | k=", kt, " N/mm",
             "  | 压到底需 ", F, " N",
             "  | 应变@", TRAVEL, "mm = ", ep * 100, "%",
             "  | 应变达1.5%时行程 ", dmax, "mm"));
}

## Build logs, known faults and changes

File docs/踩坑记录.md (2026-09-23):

# 踩坑记录

> 记录搭建工具链和提交代码过程中**真正卡住**的地方、排查过程，以及最后怎么解决的。
> 没解决的也照实写，不装作解决了。

---

## 坑 1：`git push` 到 Gitee 一直被拒绝（Permission denied）

**这是本次卡得最久的一个问题。**

### 现象

配置好 Gitee 远程仓库后推送，被直接拒绝：

```console
$ ssh -T git@gitee.com
git@gitee.com: Permission denied (publickey).
```

连不上就是连不上，没有提示「你是哪个用户」，也没有任何引导。
这句话看上去像是网络不通，很容易让人以为是代理或者防火墙的问题。

### 排查过程

一开始的方向是错的 —— 因为「拒绝访问」这四个字太像网络故障了，所以先去查网络：

1. 检查 HTTPS 能不能通：
   ```console
   $ git ls-remote https://gitee.com/oschina/git-osc.git HEAD
   ```
   能正常返回结果 → **说明网络是通的**，Gitee 服务器访问得到，问题不在网络上。

2. 既然网络没问题，那就看认证环节。执行：
   ```console
   $ ssh -vT git@gitee.com
   ```
   在调试输出里看到关键一步：SSH 确实连上了服务器，服务器也发来了认证请求，
   但客户端**没有一把服务器认可的密钥**，所有尝试的密钥都被拒，最后报 `Permission denied (publickey)`。

**结论**：`Permission denied (publickey)` 不是「连不上」，而是「连上了，但服务器不认识你」。
这两件事报错很像，但原因完全不同。这个区分是解开问题的关键。

### 根本原因

本机 `~/.ssh/` 下确实有一对密钥（`id_rsa` / `id_rsa.pub`），
但**这把公钥只加到了 GitHub 账号，没有加到 Gitee 账号**。

所以：

- 连 GitHub → 服务器认识这把钥匙 → 通过 ✅
- 连 Gitee → 服务器没见过这把钥匙 → 拒绝 ❌

公钥就是一把锁的钥匙，**在哪个平台上用，就要把公钥复制到哪个平台的账号设置里**。
一把钥匙只能开它登记过的门，换一个平台要重新登记一次。这一步我一开始漏了。

### 怎么解决的

验证了这个判断：对 GitHub 执行同样的命令，直接认出身份：

```console
$ ssh -T git@gitee.com
git@gitee.com: Permission denied (publickey).

$ ssh -T git@github.com
Hi Archer-redA! You've successfully authenticated, but GitHub does not provide shell access.
```

同一把密钥、同一台机器，**GitHub 通过而 Gitee 拒绝**，直接印证了「公钥没在 Gitee 登记」这个结论。

解决路径有两条：

- **方案 A（采用）**：改用 GitHub 托管本仓库 —— 密钥已经登记好，认证一次通过，不再折腾。
  项目仓库地址：<https://github.com/Archer-redA/from-code-to-physical>
- **方案 B（备选，如果之后需要 Gitee）**：把公钥内容
  （`cat ~/.ssh/id_rsa.pub` 的输出）完整复制，粘到 Gitee 的
  「设置 → 安全设置 → SSH 公钥」里保存，之后 `ssh -T git@gitee.com` 就会返回成功提示。

### 学到的

**看到 `Permission denied` 先别急着怀疑网络，先分清是「连不上」还是「不被认识」。**
用 `ssh -T` 测一下目标平台的认证状态，几秒钟就能定位，
比在代理和防火墙设置里绕半天有效得多。

---

## 坑 2：SSH 的 22 端口不通，改用 443 端口

**现象**：按默认方式连 GitHub 时，SSH 连接超时、卡住不动。

**原因**：GitHub 的标准 SSH 端口是 22，但在国内网络环境下这个端口经常被阻断。

**解决**：GitHub 官方提供了备用入口 `ssh.github.com:443`，把 SSH 流量伪装成 HTTPS 流量出去。
在 `~/.ssh/config` 里加上：

```
Host github.com
    Hostname ssh.github.com
    Port 443
    User git
```

这样执行 `git push` 时，SSH 会自动走 443 端口，绕过对 22 端口的限制。
配置写一次就一劳永逸，之后所有 GitHub 的操作都自动走这条路。

**这个坑的价值**：它解释了为什么「配好了密钥却还是连不上」——
密钥对但端口不通，同样推不上去。认证（钥匙对不对）和连通（路通不通）是两个独立的问题，
排查时要分开验证。

---

## 一句话总结

**卡得最久的是 Gitee 的 `Permission denied (publickey)`：一直以为是网络问题，
最后发现是公钥只加到了 GitHub、没加到 Gitee；用 `ssh -T` 测出两边结果不同才定位到原因。
解决方案是改用 GitHub（密钥已登记），备选方案是把公钥补加到 Gitee。**

---

*记录人：张涛 · 软件工程*

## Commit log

2026-09-23 chore: 初始化课程仓库，添加 .gitignore
2026-09-23 docs: 添加 README，说明个人情况与学期项目目标
2026-09-23 docs: 添加需求与验收标准，明确期末验收条件
2026-09-23 docs: 添加工具链搭建与环境验证记录
2026-09-23 docs: 记录 SSH 密钥与 22 端口踩坑及解决方案
2026-09-23 feat(hardware): 添加名字戒指的参数化建模脚本
    [ring.scad]
2026-09-23 feat(tools): 添加 STL 水密性与流形校验工具
2026-09-23 feat(hardware): 导出可打印的戒指网格，水密流形校验通过
    [ring.stl]
2026-09-23 docs(hardware): 添加戒指四个视角的预览图
2026-09-23 docs(hardware): 记录尺寸、打印参数、校验结果与建模取舍
2026-09-23 docs: 更新 README，补充硬件模块、建模工具链与打印环境
2026-09-23 docs(hardware): 添加戒指实物照片，压缩至 933KB 并清除 EXIF
2026-09-23 docs(hardware): 补录实际打印耗时、实物信息与层高差异观察
2026-09-23 docs: 在 README 中展示戒指实物照片并更新进度
2026-09-23 docs(hardware): 补录实物打印效果评估与设计归因
2026-09-23 docs: 更新戒指打印结果状态为效果良好
2026-09-23 docs: 学期项目范围修订为一体打印可动模型，重写验收标准
2026-09-23 docs: 同步 README 的学期目标、机构难点分析与进度计划
2026-09-23 feat(macropad): 添加单键柔性机构测试片，一片三个变体验证刚度
    [key-test.scad]
2026-09-23 feat(tools): STL 校验工具增加连通分量检测，防一体打印件出现散件
2026-09-23 feat(macropad): 导出测试片 STL，水密流形且三变体内部各自连通
    [key-test.stl]
2026-09-23 docs(macropad): 添加测试片等轴测、剖视与俯视预览图
2026-09-23 docs(macropad): 记录机构原理、应变计算、止挡设计与打印测试方法
